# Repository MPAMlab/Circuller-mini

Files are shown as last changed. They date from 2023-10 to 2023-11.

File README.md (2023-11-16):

# Circuller-mini

A small &amp; round game controller that uses a 5.5' touchscreen and few buttons.

[中文文档](Readme-CN.md) (will be written after the project is complete)

## Requirements

- 3D printed cases [Print details](1.%20Model/readme.md)
- Waveshare 5.5inch 1440x2560 LCD
- Cables
    - HDMI 
    - micro-USB to USB-A x2 for Touch Display Power&Touch
    - USB-C cable for PCB
    - XH2.54-3pin cable
 
- M3 screws

- PCB (probably no perfboard support)
- Keycaps (print in the model folder or buy existing low-profiled keycaps) x8

### PCB BOM

All capacitors and resistors are in the 0603 package.

Board 1:

- Gateron low-profiled key switch KS-33 / any other switch compatible x8
- 2x1x0.6mm switch button for reset x1
- WS2812B 6028/3528 RGB LED x8
- ATMEGA32U4 (needed to be bootloader pre-loaded)
- 1uF Capacitor x1
- 22pF Capacitor x2
- 100nF Capacitor x12
- 470nF Capacitor x1
- 10k ohm Resistor x2
- 22 ohm Resistor x2
- 5.1k ohm Resistor x2
- 2.5A/32V FUSE 0805 x1
- ZMM3V6 diode x2
- XH2.54-WI-3P x1
- TYPE-C 16PIN connector x1
- 16MHZ Oscillator x1

Board 2 x3:

- WS2812B 6028/3528 RGB LED x3
- XH2.54-WI-3P x5
- 100nF Capacitor x3

## PCB detail

TBD

## Assemble

TBD

## Firmware load

TBD

## Windows tool config.ini

Tested work on Wireshark 5.5-inch 2k display.

```
[Config]
1=Circuller
2=2250
3=1710
4=-165
5=0
```

## TODO

- rewrite the code
    - reorder LED part
    - rewrite debounce, reference: https://github.com/qmk/qmk_firmware/blob/master/docs/feature_debounce_type.md
    
- Redo the modeling
- Model the case (probably two versions: 1. plain like a tablet, 2. assemble like a real wash machine)

## Credit

This design and repository are not meant to violate any copyrighted content.

No games are/will be tested, and I am unaware of which game this controller can work with.

Some references: 

LED support: https://github.com/Sucareto/Mai2Touch

Modeling reference: https://github.com/xiaopeng12138/MaiDXR

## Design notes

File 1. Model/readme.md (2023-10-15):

This model references: https://github.com/xiaopeng12138/MaiDXR

print details:

parts you'll need:

1. stand.stl
2. shell.stl
3. wheel-base.stl
4. wheel-lid.stl
5. keycap.stl x 8

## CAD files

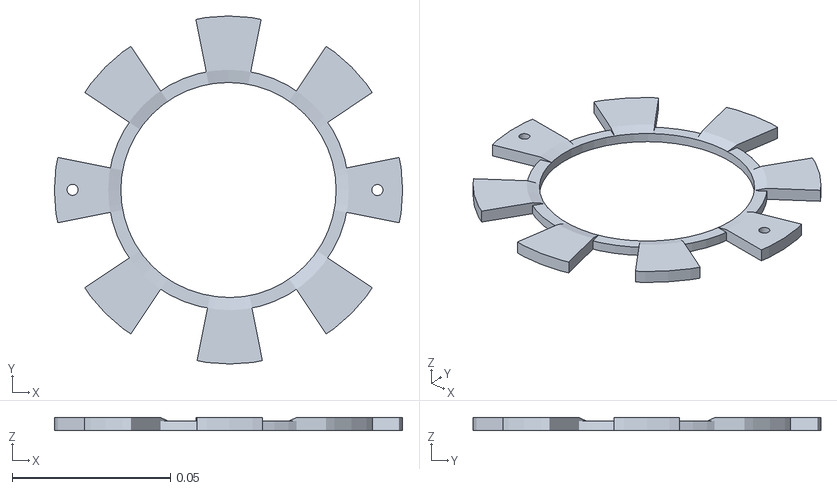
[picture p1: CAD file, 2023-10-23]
1. Model/wheel-lid-version-0-1.stl
0.11 x 0.11 x 0.004

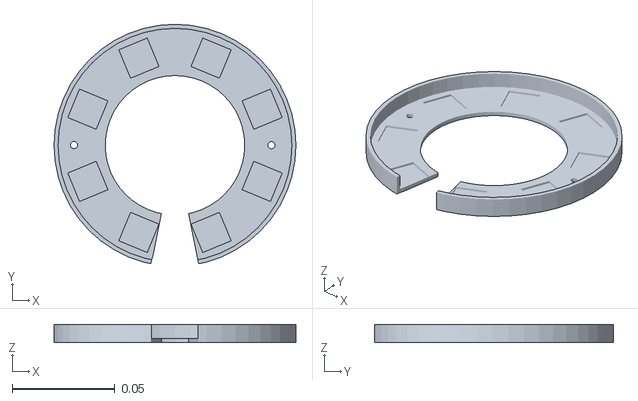
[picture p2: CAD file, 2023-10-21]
1. Model/wheel-base-version-0-1.stl
0.118 x 0.117 x 0.009

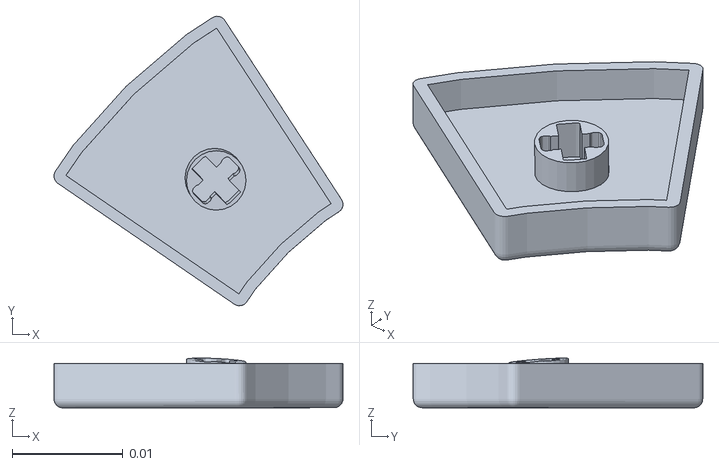
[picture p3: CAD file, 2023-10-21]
1. Model/keycap-version-1.stl
0.0261 x 0.0262 x 0.00451

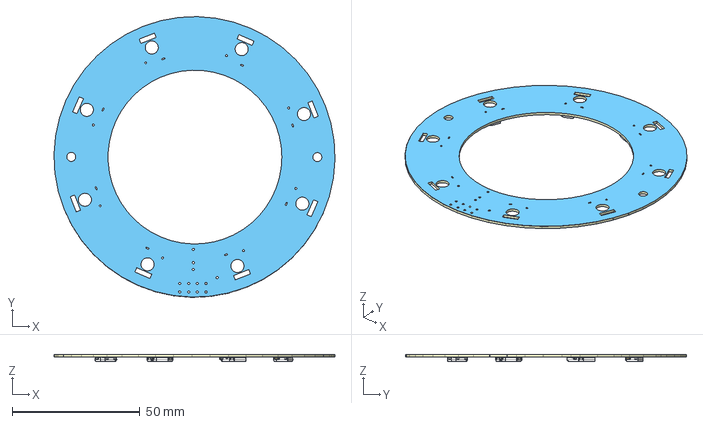
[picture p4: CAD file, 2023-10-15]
1. Model/3D_PCB_rev0.3.step
110.0 x 109.9 x 2.60 mm

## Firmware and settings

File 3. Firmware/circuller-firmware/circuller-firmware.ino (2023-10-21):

#include "Keyboard.h"
#include "FastLED.h"

// Define the button pins
#define BUTTON_W_PIN 3
#define BUTTON_E_PIN 4
#define BUTTON_D_PIN 5
#define BUTTON_C_PIN 6
#define BUTTON_X_PIN 7
#define BUTTON_Z_PIN 8
#define BUTTON_A_PIN 9
#define BUTTON_Q_PIN 10

#if defined(__AVR_ATmega32U4__) || defined(ARDUINO_SAMD_ZERO)
#pragma message "当前的开发板是 ATmega32U4 或 SAMD_ZERO"
#define SerialDevice SerialUSB
#define LED_PIN 13

#elif defined(ARDUINO_ESP8266_NODEMCU_ESP12E)
#pragma message "当前的开发板是 NODEMCU_ESP12E"
#define SerialDevice Serial
#define LED_PIN D5

#elif defined(ARDUINO_NodeMCU_32S)
#pragma message "当前的开发板是 NodeMCU_32S"
#define SerialDevice Serial
#define LED_PIN 13

#else
#error "未经测试的开发板，请检查串口和阵脚定义"
#endif

#define NUM_LEDS 11
CRGBArray<NUM_LEDS> leds;

// Define the LED order
int ledOrder[8] = {3, 2, 1, 0, 7, 6, 5, 4};
//int ledOrder[8] = {0, 1, 2, 3, 4, 5, 6, 7};
enum {
  LedGs8Bit = 0x31,//49
  LedGs8BitMulti = 0x32,//50
  LedGs8BitMultiFade = 0x33,//51
  LedFet = 0x39,//57
  LedGsUpdate = 0x3C,//60
  LedDirect = 0x82,
};

typedef union {
  uint8_t base[64];
  struct {
    struct {
      uint8_t dstNodeID;
      uint8_t srcNodeID;
      uint8_t length;
      uint8_t cmd;
    };
    union {
      struct { //39
        uint8_t color[11][3];//CRGB
      };
      struct { //9
        uint8_t BodyLed;
        uint8_t ExtLed;
        uint8_t SideLed;
      };
      struct { //LedGs8Bit
        uint8_t index;
        uint8_t r;
        uint8_t g;
        uint8_t b;
      };
      struct { //LedGs8BitMulti,LedGs8BitMultiFade
        uint8_t start;
        uint8_t end;//length
        uint8_t skip;
        uint8_t mr;
        uint8_t mg;
        uint8_t mb;
        uint8_t speed;
      };
    };
  };
} Packet;

static Packet req;

static uint8_t len, r, checksum;
static bool escape = false;

static uint8_t packet_read() {
  while (SerialDevice.available()) {
    r = SerialDevice.read();
    if (r == 0xE0) {
      len = 0;
      checksum = 0;
      continue;
    }
    if (r == 0xD0) {
      escape = true;
      continue;
    }
    if (escape) {
      r++;
      escape = false;
    }

    if (len - 3 == req.length && checksum == r) {
      return req.cmd;
    }
    req.base[len++] = r;
    checksum += r;
  }
  return 0;
}

void setup() {
  // Initialize buttons as input with internal pullup resistor
  pinMode(BUTTON_W_PIN, INPUT_PULLUP);
  pinMode(BUTTON_E_PIN, INPUT_PULLUP);
  pinMode(BUTTON_D_PIN, INPUT_PULLUP);
  pinMode(BUTTON_C_PIN, INPUT_PULLUP);
  pinMode(BUTTON_X_PIN, INPUT_PULLUP);
  pinMode(BUTTON_Z_PIN, INPUT_PULLUP);
  pinMode(BUTTON_A_PIN, INPUT_PULLUP);
  pinMode(BUTTON_Q_PIN, INPUT_PULLUP);

  // Begin keyboard emulation
  Keyboard.begin();
  FastLED.addLeds<WS2812B, LED_PIN, GRB>(leds, NUM_LEDS);
  FastLED.setBrightness(30);
  FastLED.clear();
  SerialDevice.begin(115200);
  leds[ledOrder[req.index]] = 0xFFFFFF;
  FastLED.delay(1000);

}

unsigned long fade_start, fade_end, progress;
uint8_t led_start, led_end, fade_tag;
CRGB fade_prev, fade_taget;

void loop() {
  // If a button is pressed (LOW), emulate the corresponding key press
  if(digitalRead(BUTTON_W_PIN) == LOW) Keyboard.write('w');
  if(digitalRead(BUTTON_E_PIN) == LOW) Keyboard.write('e');
  if(digitalRead(BUTTON_D_PIN) == LOW) Keyboard.write('d');
  if(digitalRead(BUTTON_C_PIN) == LOW) Keyboard.write('c');
  if(digitalRead(BUTTON_X_PIN) == LOW) Keyboard.write('x');
  if(digitalRead(BUTTON_Z_PIN) == LOW) Keyboard.write('z');
  if(digitalRead(BUTTON_A_PIN) == LOW) Keyboard.write('a');
  if(digitalRead(BUTTON_Q_PIN) == LOW) Keyboard.write('q');

  // Add a small delay to prevent button bouncing
  delay(65);

  switch (packet_read()) {
    case LedGs8Bit:
      leds[req.index] = CRGB(req.r, req.g, req.b);
      break;

    case LedGs8BitMulti:
      if (req.end == 0x20) {
          req.end = NUM_LEDS;
      }
      for (uint8_t i = req.start; i < req.end; i++) {
          leds[ledOrder[i]] = CRGB(req.mr, req.mg, req.mb);
      }
      fade_prev = CRGB(req.mr, req.mg, req.mb);
      fade_tag = 0;


    case LedGs8BitMultiFade:
      fade_taget = CRGB(req.mr, req.mg, req.mb);
      fade_start = millis();
      fade_end = fade_start + (4095 / req.speed * 8);
      led_start = req.start;
      led_end = req.end - 1;
      fade_tag = 1;
      break;

    case LedFet://框体灯，只有白色，值代表亮度，会多次发送实现渐变，需要立刻刷新
      leds[8] = blend(0x000000, 0xFFFFFF, req.BodyLed);
      leds[9] = blend(0x000000, 0xFFFFFF, req.ExtLed);//same as BodyLed
      leds[10] = blend(0x000000, 0xFFFFFF, req.SideLed);//00 or FF
      FastLED.show();
      break;

    case LedGsUpdate://提交灯光数据
      FastLED.show();
      break;
  }

  if (!fade_tag)return;
  if (millis() > fade_end) {
    progress = 255;
    fade_tag = 0;
  } else {
    progress = map(millis(), fade_start, fade_end, 0, 255);
  }
  for (uint8_t i = led_start; i <= led_end; i++) {
      leds[ledOrder[i]] = blend(fade_prev, fade_taget, progress);
  }
  FastLED.show();

}

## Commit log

2023-10-10 upload 1st revision schematic
2023-10-10 First version of PCB
2023-10-11 PCB rev 0.3f update
2023-10-11 PCB to Rev 0.3f
2023-10-11 added drill hole
2023-10-15 Model Upload
    [keycap-testprint.stl, wheel-base-rev0-1.stl, wheel-base-testprint.stl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]
2023-10-15 PCB model update
    [3D_PCB5_2023-10-15.step]
2023-10-21 going arduino IDE
2023-11-15 update rev 1.2 board
    changed board size to 10x10cm
2023-11-15 update model file for new pcb
    [3D_PCB_rev0.3.step]
2023-11-16 Critical update PCB to rev1.3
2023-11-16 update gerber and led board
2023-11-23 Update PCB Design
    changed GND & VCC to 10mil
    D+ & D- now are length matching (MISO and MOSI are also matching even tho not necessary)
    optimized some cable routing
2023-11-24 pcb rev1.6
    moved port to places that not on the screen
2023-11-25 update pcb model
